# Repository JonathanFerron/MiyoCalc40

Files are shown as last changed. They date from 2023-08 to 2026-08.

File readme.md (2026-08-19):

# MiyoCalc40

RPN calculator

This is a project for a trough-hole only RPN calculator with a flexible configuration. The idea is for it to be minimalist, meant as a complement to other tools that the 
user would typically have on hand (computer, formula cheat sheet, etc.) rather than as a replacement, and made with easy to solder through-hole components.

I would like to give credit to the work of the following individuals which has served as inspiration for this project:

- Alex Garza for work done on the Voyager form-factor RPN calculators: https://paxer.net/voyager/
- Anton Poluektov for work done on the OpenRPNCalc calculator: https://github.com/apoluekt/OpenRPNCalc

The MiyoCalc40 **PCB work** is licensed under a
[Creative Commons Attribution-NonCommercial-ShareAlike 4.0 International License][cc-by-nc-sa].

[][cc-by-nc-sa]

[cc-by-nc-sa]: http://creativecommons.org/licenses/by-nc-sa/4.0/
[cc-by-nc-sa-image]: https://licensebuttons.net/l/by-nc-sa/4.0/88x31.png
[cc-by-nc-sa-shield]: https://img.shields.io/badge/License-CC%20BY--NC--SA%204.0-lightgrey.svg

The MiyoCalc40 **Firmware** is licensed under the GNU General Public License version 3:
Copyright (C) 2026 Jonathan Ferron

This program is free software: you can redistribute it and/or modify
it under the terms of the GNU General Public License as published by
the Free Software Foundation, either version 3 of the License, or (at your option) any later version.

This program is distributed in the hope that it will be useful,
but WITHOUT ANY WARRANTY; without even the implied warranty of
MERCHANTABILITY or FITNESS FOR A PARTICULAR PURPOSE.  See the
GNU General Public License for more details.

You should have received a copy of the GNU General Public License
along with this program.  If not, see <http://www.gnu.org/licenses/>.

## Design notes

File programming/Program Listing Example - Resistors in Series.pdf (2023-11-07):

Program Listing | Program Keycodes: 67 bytes in total
~~R
{- Calculate current and voltage drop through multiple resistors in series
Input: V(T) in X (stack) | I = V/R
R(i) in Rxn (registers)
Output: I(T) in X
V(i) in Rxn -}
0 | @@ R(T) initialized to 0.00 in X, V(T) pushed to Y | KC_0
ENTER | @@ R(T) pushed to Y, V(T) pushed to Z | KC_ENTER
FOR | @@ loop over rows 0 to 3 | KCP_FOR
CNT_INIT 1 # 0 | @@ Cnt1 = 0 | KCP_CNT_INIT KC_1 | KCP_NUMSEP KC_0
COUNT< 4 | @@ loop as long as Cnt1 is < 4 | KCP_CLESSN | KC_4
FOR | @@ loop over columns 0 to 9 | KCP_FOR
CNT_INIT 0 # 0 | @@ Cnt0 = 0 | KCP_CNT_INIT KC_0 | KCP_NUMSEP KC_0
COUNT< 10 | @@ loop as long as Cnt0 is < 10 | KCP_CLESSN | KC_1 | KC_0
RCL CNTREF 1 CNTREF 0 | @@ Pull R(i)(j)=R(Cnt1)(Cnt0) into X | KC_RCLREG | KCP_CNT_REF KC_1 | KCP_CNT_REF KC_0
IF X<>0 | KCP_IF | KCP_XNOT0
+ | @@ iteratively calc R(T) += R(i,j) | KC_ADD
ELSE | KCP_ELSE
CYCLE | @@ silly example to show use of CYCLE instruction | KCP_CYCLE
ENDIF | KCP_ENDIF
NEXT 1 | @@ next column | KCP_NEXT | KC_1
NEXT 1 | @@ next row | KCP_NEXT | KC_1

{- R(T) now in X. Calculate I, duplicate it to Y, and use it to calc the V(i) -}
/ | @@ I in X, R(T) in Y | KC_DIV
ENTER | @@ I in X and Y, R(T) in Z | KC_ENTER
FOR | @@ loop over rows 0 to 3 | KCP_FOR
CNT_INIT 1 # 0 | @@ Cnt1 = 0 | KCP_CNT_INIT KC_1 | KCP_NUMSEP KC_0
COUNT< 4 | @@ loop as long as Cnt1 is < 4 | KCP_CLESSN | KC_4
FOR | @@ loop over columns 0 to 9 | KCP_FOR
CNT_INIT 0 # 0 | @@ Cnt0 = 0 | KCP_CNT_INIT KC_0 | KCP_NUMSEP KC_0
COUNT< 10 | @@ loop as long as Cnt0 is < 10 | KCP_CLESSN | KC_1 | KC_0
RCL CNTREF 1 CNTREF 0 | @@ Pull R(i)(j)=R(Cnt1)(Cnt0) into X | KC_RCLREG | KCP_CNT_REF KC_1 | KCP_CNT_REF KC_0
* | @@ Calc V(i) in X, I in Y, R(T) in Z | KC_MULT
STO CNTREF 1 CNTREF 0 | @@ Store V(i) in Reg(i)(j) | KC_STOREG | KCP_CNT_REF KC_1 | KCP_CNT_REF KC_0
DROP | @@ Drop X: I will be in X, R(T) in Y | KC_DROPX
ENTER | @@ Duplicate I into Y, push R(T) to Z | KC_ENTER
NEXT 1 | @@ next column | KCP_NEXT | KC_1
NEXT 1 | @@ next row | KCP_NEXT | KC_1
DROP | @@ Drop duplicate I | KC_DROPX

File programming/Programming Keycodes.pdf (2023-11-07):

KCP_IF | 0xD0 | KCP_XEQU0 | 0xE0 // x=0?
KCP_ELSE | 0xD1 | KCP_XNOT0 | 0xE1 // x <> 0?
KCP_ENDIF | 0xD2 | KCP_XLESS0 | 0xE2 // x < 0?
| | KCP_XLEEQ0 | 0xE3 // x <= 0?
KCP_CASE | 0xD3 | KCP_XGREA0 | 0xE4 // x > 0?
KCP_WHEN | 0xD4 | KCP_GREQ0 | 0xE5 // x >= 0?
KCP_OTHER | 0xD5
KCP_ENDCAS | 0xD6 // end case | KCP_XEQUY | 0xE6 // x = y?
| | KCP_CEQUN | 0xE6 // cnt = n?
KCP_SETFLAG 0xD7 | KCP_XNOTY | 0xE7 // x <> y?
KCP_CLRFLAG 0xD8 | KCP_CNOTN | 0xE7
| | KCP_XLESSY | 0xE8
KCP_FOR | 0xD9 | KCP_CLESSN | 0xE8
KCP_NEXT | 0xDA | KCP_XLEEQY | 0xE9
| | KCP_CLEEQN | 0xE9
KCP_WHILE | 0xDB | KCP_XGREAY | 0xEA
KCP_WEND | 0xDC | KCP_CGREAN | 0xEA
| | KCP_XGREQY | 0xEB
KCP_DO | 0xDD | KCP_CGREQN | 0xEB
KCP_LOOPWHEN 0xDE
| | KCP_CNT_INIT
KCP_CYCLE | 0xEC | KCP_CNT_INC
KCP_EXIT | 0xED | KCP_STK_REF
| | KCP_CNT_REF
KCP_NUMSEP (#)

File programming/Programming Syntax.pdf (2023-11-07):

IF
X?0 or X?Y or Flag(n) = True (provide flag number on next instruction) do something
ELSE | | (optional)
do something else
ENDIF

note: no special keycode for 'flag(n)=true', just use KC_O to KC_7

SF(n): To set flag to true, with 'n' provided as 'next instruction' n between 0 and 7 in a 8 bit flag register
CF(n): To set flag to false, with 'n' provided as 'next instruction'

CASE
var to test (0 means X, 1 means Y, ...)
WHEN
value 1 (integers only) then optional KCP_NUMSEP keycode (#) (only required if next stmt starts with a digit)
do something | | automatically convert speace or CR to 'NumSep' when keyed from PC
WHEN | 1+ 'when' stmts | present as Carriage Return (CR) on Calculator LCD
value 2 | | optionally can show # as well on computer
do something else
OTHER | other' is optional and must be at end
do another thing
ENDCAS

FOR
CNT_INIT i (counter identifier)
init count (16 bit signed integer)
COUNT?
n (signed integer) then optional # (NumSep)
Do stuff
NEXT
increment / decrement to count (signed integer) then optional #

CND_INIT i (optional)
WHILE
X?0 or X?Y or Flag(n) = True
do stuff
CNT_INC i n # (optional, to increment Cnt(i) by n) WEND

DO
do stuff
LOOPWH
X?0 or X?Y or Flag(n) = True

EXIT instruction: force loops to return
CYCLE instruction: to force loops to loop

CNT_REF by itself, will push CNT(i) to X on the stack

@@ single line comment
{- multiple line comment -}
~~A to mark beginning of program A

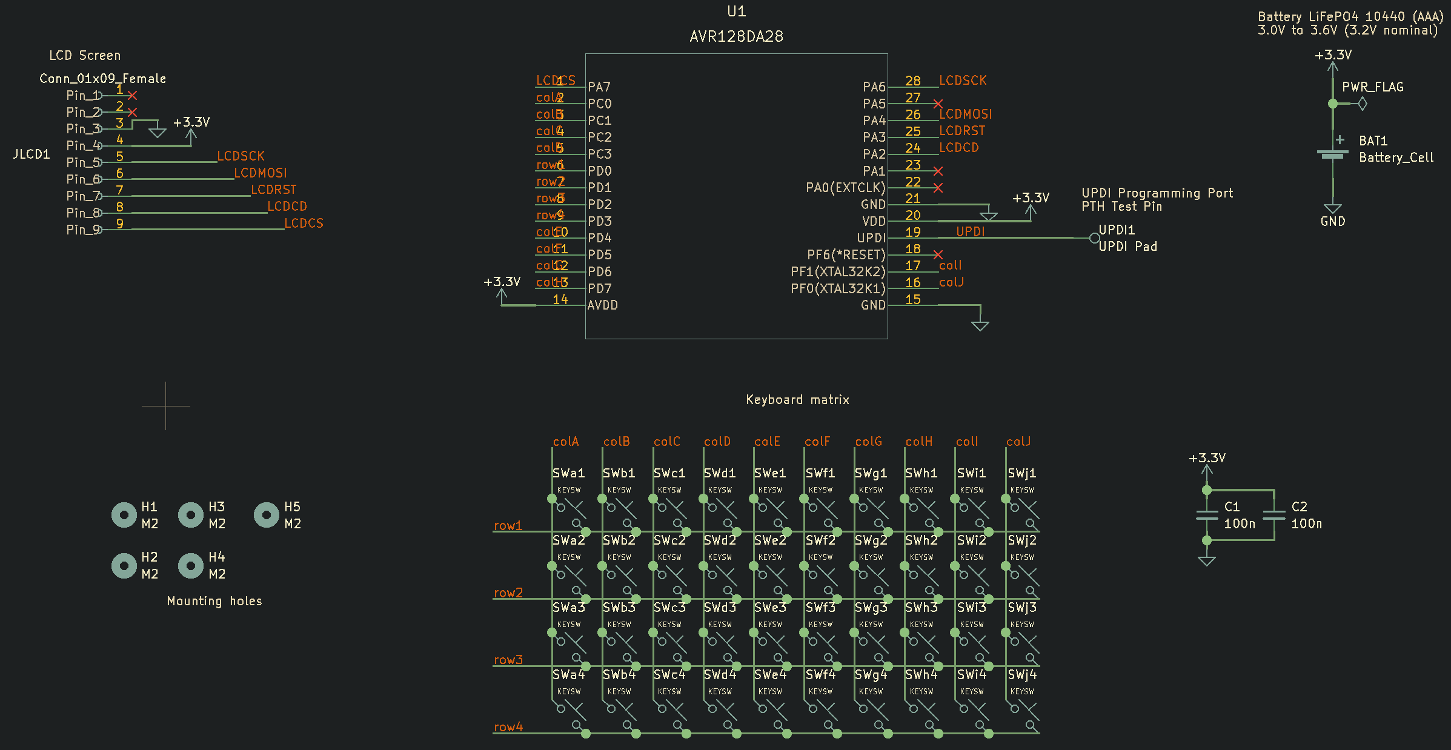
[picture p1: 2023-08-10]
pcb/printouts/Screenshot schematic.png

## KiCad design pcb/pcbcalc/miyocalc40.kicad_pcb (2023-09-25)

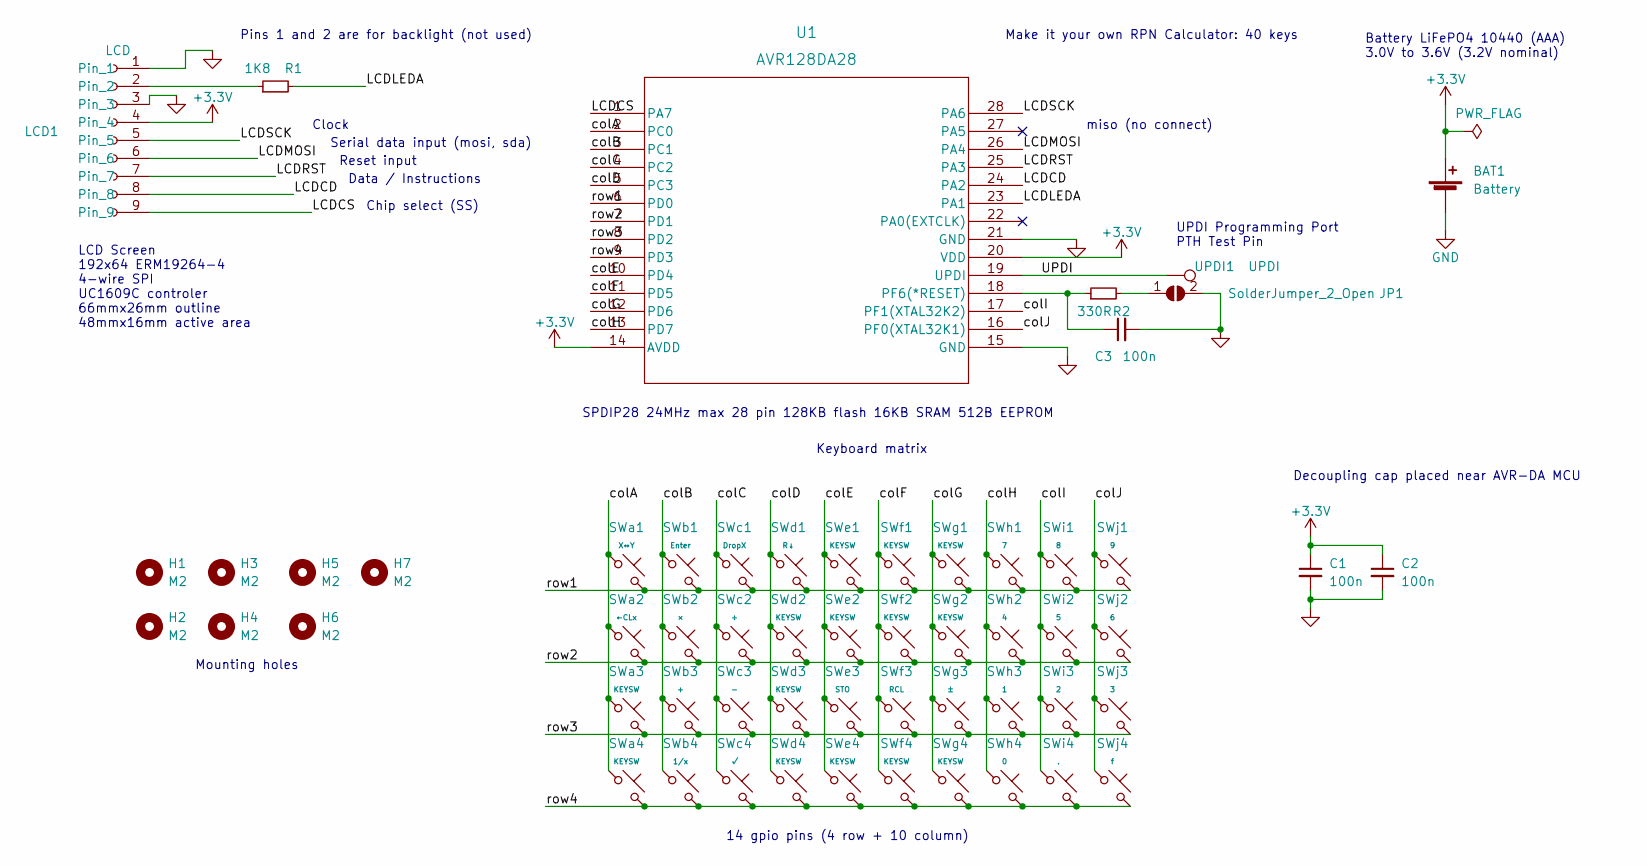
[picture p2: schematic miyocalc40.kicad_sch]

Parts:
BAT1: Battery; BatteryHolder_AAA
C1, C2, C3: 100n; C_Disc_D4.3mm_W1.9mm_P5.00mm
H1, H2, H3, H4, H5, H6, H7: M2; MountingHole
JP1: SolderJumper_2_Open; Reset Jumper
LCD1: LCD; PinSocket_1x09_P2.54mm_Vertical
R1: 1K8; R_Axial_DIN0204_L3.6mm_D1.6mm_P5.08mm_Horizontal
R2: 330R; R_Axial_DIN0204_L3.6mm_D1.6mm_P5.08mm_Horizontal
SWa1: X↔Y; SW_PUSH_6mm
SWa2: ←CLx; SW_PUSH_6mm
SWa3, SWa4: KEYSW; SW_PUSH_6mm
SWb1: Enter; SW_PUSH_6mm
SWb2: ×; SW_PUSH_6mm
SWb3: +; SW_PUSH_6mm
SWb4: 1/x; SW_PUSH_6mm
SWc1: DropX; SW_PUSH_6mm
SWc2: ÷; SW_PUSH_6mm
SWc3: -; SW_PUSH_6mm
SWc4: √; SW_PUSH_6mm
SWd1: R↓; SW_PUSH_6mm
SWd2, SWd3, SWd4: KEYSW; SW_PUSH_6mm
SWe1, SWe2, SWe4: KEYSW; SW_PUSH_6mm
SWe3: STO; SW_PUSH_6mm
SWf1, SWf2, SWf4: KEYSW; SW_PUSH_6mm
SWf3: RCL; SW_PUSH_6mm
SWg1, SWg2, SWg4: KEYSW; SW_PUSH_6mm
SWg3: ±; SW_PUSH_6mm
SWh1: 7; SW_PUSH_6mm
SWh2: 4; SW_PUSH_6mm
SWh3: 1; SW_PUSH_6mm
SWh4: 0; SW_PUSH_6mm
SWi1: 8; SW_PUSH_6mm
SWi2: 5; SW_PUSH_6mm
SWi3: 2; SW_PUSH_6mm
SWi4: .; SW_PUSH_6mm
SWj1: 9; SW_PUSH_6mm
SWj2: 6; SW_PUSH_6mm
SWj3: 3; SW_PUSH_6mm
SWj4: f; SW_PUSH_6mm
U1: AVR128DA28; DIP-28_W7.62mm_Socket
UPDI1: UPDI; UPDI Port

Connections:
+3V3: BAT1.1 (+), C1.1, C2.1, LCD1.4, U1.14 (AVDD), U1.20 (VDD)
/LCDCD: LCD1.8, U1.24 (PA2)
/LCDCS: LCD1.9, U1.1 (PA7)
/LCDLEDA: R1.2, U1.23 (PA1)
/LCDMOSI: LCD1.6, U1.26 (PA4)
/LCDRST: LCD1.7, U1.25 (PA3)
/LCDSCK: LCD1.5, U1.28 (PA6)
/UPDI: U1.19 (UPDI), UPDI1.1
/colA: SWa1.1, SWa2.1, SWa3.1, SWa4.1, U1.2 (PC0)
/colB: SWb1.1, SWb2.1, SWb3.1, SWb4.1, U1.3 (PC1)
/colC: SWc1.1, SWc2.1, SWc3.1, SWc4.1, U1.4 (PC2)
/colD: SWd1.1, SWd2.1, SWd3.1, SWd4.1, U1.5 (PC3)
/colE: SWe1.1, SWe2.1, SWe3.1, SWe4.1, U1.10 (PD4)
/colF: SWf1.1, SWf2.1, SWf3.1, SWf4.1, U1.11 (PD5)
/colG: SWg1.1, SWg2.1, SWg3.1, SWg4.1, U1.12 (PD6)
/colH: SWh1.1, SWh2.1, SWh3.1, SWh4.1, U1.13 (PD7)
/colI: SWi1.1, SWi2.1, SWi3.1, SWi4.1, U1.17 (PF1(XTAL32K2))
/colJ: SWj1.1, SWj2.1, SWj3.1, SWj4.1, U1.16 (PF0(XTAL32K1))
/row1: SWa1.2, SWb1.2, SWc1.2, SWd1.2, SWe1.2, SWf1.2, SWg1.2, SWh1.2, SWi1.2, SWj1.2, U1.6 (PD0)
/row2: SWa2.2, SWb2.2, SWc2.2, SWd2.2, SWe2.2, SWf2.2, SWg2.2, SWh2.2, SWi2.2, SWj2.2, U1.7 (PD1)
/row3: SWa3.2, SWb3.2, SWc3.2, SWd3.2, SWe3.2, SWf3.2, SWg3.2, SWh3.2, SWi3.2, SWj3.2, U1.8 (PD2)
/row4: SWa4.2, SWb4.2, SWc4.2, SWd4.2, SWe4.2, SWf4.2, SWg4.2, SWh4.2, SWi4.2, SWj4.2, U1.9 (PD3)
GND: BAT1.2 (-), C1.2, C2.2, C3.2, JP1.2 (B), LCD1.1, LCD1.3, U1.15 (GND), U1.21 (GND)
unnamed: C3.1, R2.1, U1.18 (PF6(*RESET))
unnamed: JP1.1 (A), R2.2
unnamed: LCD1.2, R1.1

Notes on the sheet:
Pins 1 and 2 are for backlight (not used)
miso (no connect)
Battery LiFePO4 10440 (AAA) 3.0V to 3.6V (3.2V nominal)
Decoupling cap placed near AVR-DA MCU
Clock
Make it your own RPN Calculator: 40 keys
Data / Instructions
Reset input
14 gpio pins (4 row + 10 column)
LCD Screen 192x64 ERM19264-4 4-wire SPI UC1609C controler 66mmx26mm outline 48mmx16mm active area
UPDI Programming Port PTH Test Pin
Serial data input (mosi, sda)
Keyboard matrix
Mounting holes
SPDIP28 24MHz max 28 pin 128KB flash 16KB SRAM 512B EEPROM
Chip select (SS)

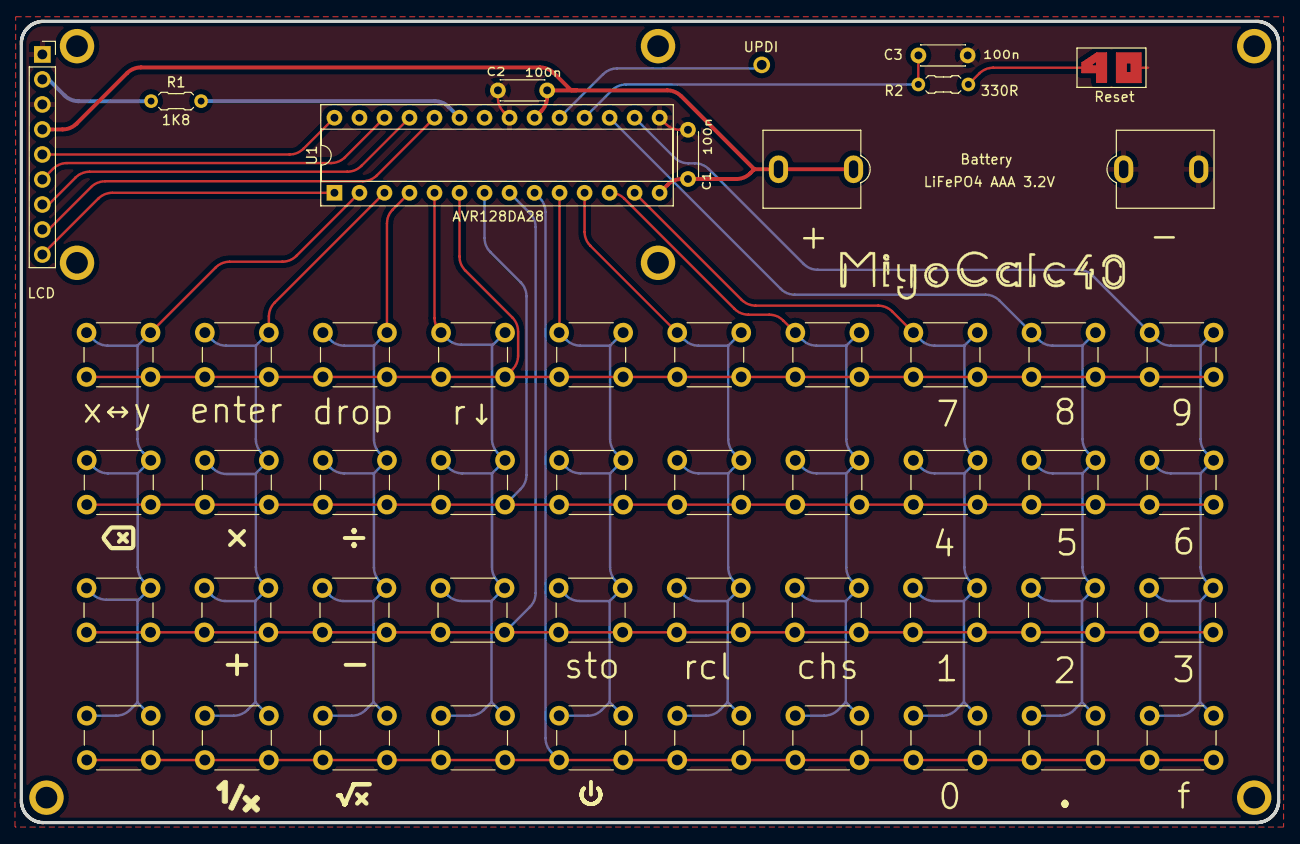
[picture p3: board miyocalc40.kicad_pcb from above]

Board: 2 copper layers, 127.7 x 81.4 mm, 57 parts (0 on the bottom side), 26 nets.

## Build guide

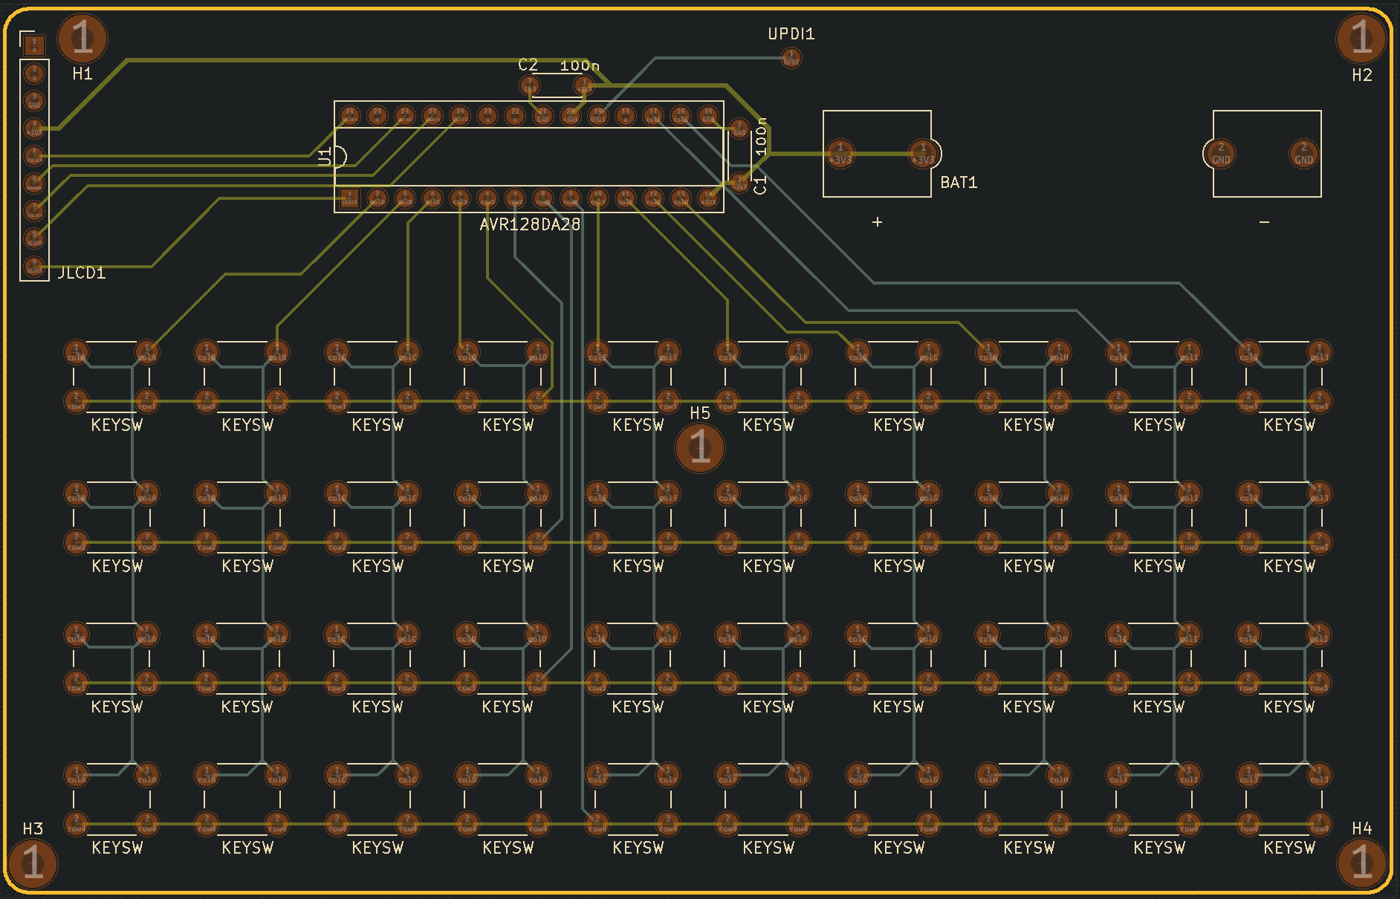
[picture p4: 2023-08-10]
pcb/printouts/Screenshot pcb.png

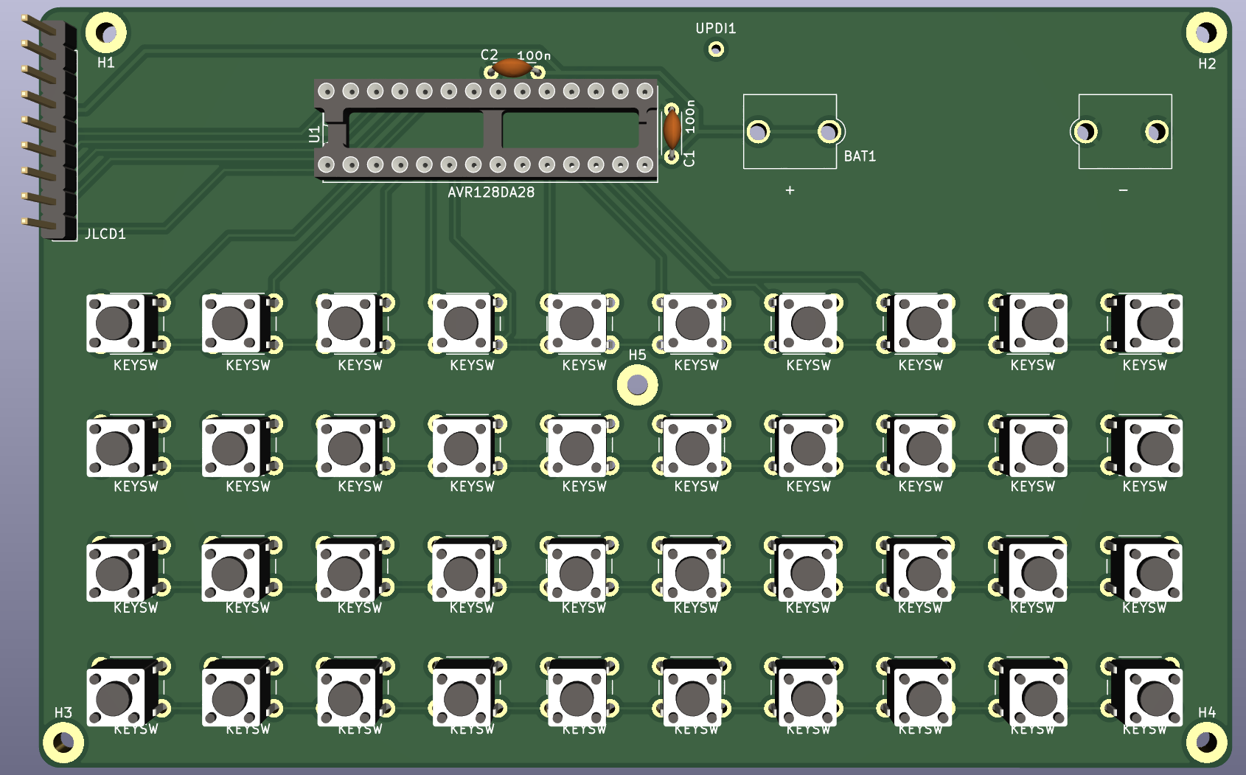
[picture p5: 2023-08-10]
pcb/printouts/miyocalc40 3D.png

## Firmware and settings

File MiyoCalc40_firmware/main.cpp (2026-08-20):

/*
   To build and flash the firmware: `make` then `make flash` from MiyoCalc40_firmware/ (see
   CLAUDE.md and makefile for the full make target list).

   main: main program loop

   matrix: matrix scanning code

   cards: contains mapping from matrix key positions to 'actions' for each 'mode'

   calc: number crunching mode

   lcd: to control lcd

   fonts: fonts bitmaps

   programming: programming mode

   config: configuration mode
     util: to display battery voltage, etc

   backlight: to turn on/off backlight and set pwm duty cycle

   avrducore: clock/CCP/fuses/GPIO/SPI0
*/

/* Other notes:

  MCU draws about 6.0mA at 3.2V when actively running at 24 MHz

*/

#include <stdbool.h>
#include <avr/io.h>
#include <avr/interrupt.h>
#include <avr/sleep.h>
#include <util/delay.h>

#include "matrix.h"
#include "lcd.h"
#include "main.h"
#include "cards.h"
#include "calc.h"
#include "util.h"
#include "clock.h"
#include "gpio.h"
#include "backlight.h"

#define LCD_Default_Contrast 0x0C // Default LCD constrast: 0x0A to 0x20 tend to work well.

// GPIO 5-wire SPI interface

#define LCD_CS GPIO_PIN(PORTA, 7)  // AVR pin connected to LCD CS pin
#define LCD_CD GPIO_PIN(PORTA, 2) // AVR pin connected to LCD CD pin
#define LCD_RST GPIO_PIN(PORTA, 3) // AVR pin connected to LCD Reset pin

// Global variables
ERM19264_UC1609_T  mylcd(LCD_CD, LCD_RST, LCD_CS); // construct object using hardware SPI: CD, RST, CS

int lcdon;  // to track if lcd is turned on or not, to do: change this to 'calcon'

int main()
{ clock_init(); // avrducore/clock.c: 24MHz OSCHF, no prescaler, CPUINT defaults

  /* Insert here any code that needs to run before interrupts are enabled but after all other core initialization. */
  sei();  // enable interrupts (could consider turning on interupts only after the setup code below, if it matters at all).

  setupMCU();
  setupMatrix();

  setupLCD();

  backlight_init();
  setupBattVoltMonitor();

  calc_init();

  for(;;)
    loop();
}

void setupMCU()
{ // ADC/AC/VREF setup for battery voltage monitoring lives in setupBattVoltMonitor() (util.cpp),
  // called from main(). The ADC itself is left disabled there; it's only enabled for the
  // duration of a reading, by read_batt_voltage_mv().

  set_sleep_mode(SLEEP_MODE_STANDBY);
  sleep_enable();
  /* Enable BOTHEDGES interrupts for columns */
  PORTC.PIN0CTRL |= PORT_ISC_BOTHEDGES_gc;
  PORTC.PIN1CTRL |= PORT_ISC_BOTHEDGES_gc;
  PORTC.PIN2CTRL |= PORT_ISC_BOTHEDGES_gc;
  PORTC.PIN3CTRL |= PORT_ISC_BOTHEDGES_gc;
  PORTD.PIN4CTRL |= PORT_ISC_BOTHEDGES_gc;
  PORTD.PIN5CTRL |= PORT_ISC_BOTHEDGES_gc;
  PORTD.PIN6CTRL |= PORT_ISC_BOTHEDGES_gc;
  PORTD.PIN7CTRL |= PORT_ISC_BOTHEDGES_gc;
  PORTF.PIN0CTRL |= PORT_ISC_BOTHEDGES_gc;
  PORTF.PIN1CTRL |= PORT_ISC_BOTHEDGES_gc;
}

ISR(PORTC_PORT_vect)
{ /* Clear interrupt flag */
  VPORTC.INTFLAGS = PIN0_bm | PIN1_bm | PIN2_bm | PIN3_bm;
}

ISR(PORTD_PORT_vect)
{ /* Clear interrupt flag */
  VPORTD.INTFLAGS = PIN4_bm | PIN5_bm | PIN6_bm | PIN7_bm;
}

ISR(PORTF_PORT_vect)
{ /* Clear interrupt flag */
  VPORTF.INTFLAGS = PIN0_bm | PIN1_bm;
}


void setupLCD()
{ mylcd.LCDbegin(LCD_Default_Contrast); // initialize the LCD
  mylcd.LCDFillScreen(0x00, 0); // clear screen
  _delay_ms(50);
  lcdon = true;
}

/*
  go in sleep mode (enable sleep, enable bothedges interrups for all column pins) : see dxcore/megaavr/extras/powersave.md

  upon wake interupt (port isr wake-up button press wakes up the mcu from sleep)
  debounce 3ms to 20ms (10 times 2ms) using PIT (periodic interupt timer, programmed to trigger an interrupt every millisecond, lowpower_delay_ms function, set interrupt
  to fire every 32 RTC clock cycles and enable PIT, enable PIT interrupts), validating logic low level on a column each time: btn_debounce() function

  if logic low level still detected in a column
    then scan keys (scan matrix) via function call: scankb()

    if calc is off, power it up if 'on' button was pressed
    else (lcd is on)
      if in mem store, recall mode or clear mode (see the mem_recall_mode, mem_store_mode and mem_clear_mode boolean variables):
        call mem store, recall, or clear with key pos (2D), should have a max of 40 possible var : call apply_memory_rcl(uint8_t r, uint8_t c), apply_memory_sto(uint8_t r, uint8_t c) and apply_memory_clr(uint8_t r, uint8_t c)
      else
        with key position (from scankb), lookup function pointer and keycode (action struct)

        if in 'calc mode'
          if 'off' button (combination) was pressed (can tell based on action), power down
          else
            process action via function call (from function pointer): from 'action' struct from 'calc' (if in calc mode) or 'config' (if in config mode)
              provide it the keycode that was also looked up
              action in program mode, when a key is pressed to be recorded, is a function that will call another function with a keycode to log/record it
          end if
        end if
      end if
    endif

    inner loop begin (idle until key is released):
      if logic low level on any column still
        then sleep
          port isr wake-up: button is released
      end if
    end inner loop
    may want to debouce here as well (openrpncalc uses 10ms)
  end if
*/
bool press_valid = false;
void loop()
{ // go in sleep mode
  sleep_cpu();

  // debounce 10 * 2ms = 20ms
  press_valid = true;
  for(uint8_t i = 0; i < 10; i++)
  { // initialize before scanning
    keypos_c = 0xff;
    keypos_r = 0xff;
    scanKB(); // scan kb
    /* If no button is pressed, flag press as non-valid */
    if(keypos_c == 0xff && keypos_r == 0xff)
    { press_valid = false;
      break;
    }
    //lp_delay_ms(2);
    _delay_ms(2);  // to-do: chg this to PIT based delay to save power
  }  // end for loop for debouncing

  // if key press is valid, then move on to scan and process key press
  if(press_valid)
  { // scan keys
    scanKB();

    // if lcd is off, power it up if 'on' button was pressed
    if(keypos_r == ONOFFKEYPOS_R && keypos_c == ONOFFKEYPOS_C && !lcdon)
    { setupLCD();
      backlight_resume();
      lcdon = true;
      if(input.started)
        LCDDrawInput();
      else
        LCDDrawStackAndMem();

      set_sleep_mode(SLEEP_MODE_STANDBY);
      shift = baseLayer;
      keypos_c = 0xff;
      keypos_r = 0xff; // reset keypos to 'null' after action is obtained
    } // 'power on' lcd

    // if non-null keypos and calc is on:
    if(lcdon && keypos_r != 0xff)
    { // if in mem store, recall mode or clear mode
      if(mem_recall_mode || mem_store_mode || mem_clear_mode)
      { if(mem_recall_mode)
        { // process action
          // call apply_memory_rcl(uint8_t r, uint8_t c) to recall the variable to X
          apply_memory_rcl(keypos_r, keypos_c);
          keypos_c = 0xff;
          keypos_r = 0xff; // reset keypos to 'null' after action is obtained

          // reset mode to false after action has been processed
          mem_recall_mode = false;
        }
        else if(mem_store_mode)
        { // process action
          apply_memory_sto(keypos_r, keypos_c);
          keypos_c = 0xff;
          keypos_r = 0xff; // reset keypos to 'null' after action is obtained

          // reset mode to false after action has been processed
          mem_store_mode = false;
        }
        else // we're in mem clear mode
        { // process action
          apply_memory_clr(keypos_r, keypos_c);
          keypos_c = 0xff;
          keypos_r = 0xff; // reset keypos to 'null' after action is obtained

          // reset mode to false after action has been processed
          mem_clear_mode = false;
        }
        LCDDrawCalcStatus();
      }
      else // not in mem store, recall, or clear mode
      { // lookup function pointer+keycode (action struct)
        action current_action = keytoaction();
        // refresh lcd : this will become obsolete since we'll refresh the lcd from within the actions, when necessary
        /*
          mylcd.LCDFillScreen(0x00, 0); // clear screen
          mylcd.LCDChar('R' - MCFLETOFFSET, 14*0, 0*3);  // R
          mylcd.LCDChar(keypos_r, 14*1, 0 * 3);
          mylcd.LCDChar('C' - MCFLETOFFSET, 14*3, 0*3); // C
          mylcd.LCDChar(keypos_c, 14*4, 0 * 3);
        */

        keypos_c = 0xff;
        keypos_r = 0xff; // reset keypos to 'null' after action is obtained

        // process action via function call: from 'action' struct, call the function and provide it the keycode that was also looked up.
        current_action.fct(current_action.keycode);

        // if (current shift is not base layer && keycode of function that was just executed is not a layer shift keycode that corresponds to the current layer), then move back to base layer
        // config mode has no shift layers of its own, and enter_shift_base() would repaint the
        // calc status indicators over whatever config screen is currently displayed, so skip
        // all of this while in config mode.
        if(current_calc_prog_config_mode != config_mode)
        { if(!((current_action.mnemonic[0] == ACT_SHFT_F.mnemonic[0] && current_action.mnemonic[1] == ACT_SHFT_F.mnemonic[1] && shift == fLayer) ||
               (current_action.mnemonic[0] == ACT_SHFT_G.mnemonic[0] && current_action.mnemonic[1] == ACT_SHFT_G.mnemonic[1] && shift == gLayer) ||
               (current_action.mnemonic[0] == ACT_SHFT_H.mnemonic[0] && current_action.mnemonic[1] == ACT_SHFT_H.mnemonic[1] && shift == hLayer)))
          { if(lcdon)
              enter_shift_base(KC_NOP);
            else
              shift = baseLayer;
          }
        }
        else
          shift = baseLayer;
      }

      do
      { keypos_c = 0xff;
        keypos_r = 0xff;
        scanKB();
      }
      while(keypos_c != 0xff || keypos_r != 0xff);

    } // end processing of non-null keypos
  } // end processing of valid key press

} // loop()

// Battery voltage measurement (setupBattVoltMonitor() / read_batt_voltage_mv()) now lives in
// util.cpp, wired up to the 'config' mode battery-voltage screen (config.cpp). See util.cpp for
// the derivation of the VDD-in-millivolts calculation and the peripheral setup this depends on.

// if 'off' button (combination) was pressed (can tell based on action), power down lcd and configure 'sleep mode' to powerdown
void power_down(__attribute__((unused)) uint8_t keycode)
{ mylcd.FullLCDPowerDown();
  backlight_suspend(); // see backlight.h: TCA0 must not be left running into Power-Down sleep
  lcdon = false;
  //LCDDrawStackAndMem();

  set_sleep_mode(SLEEP_MODE_PWR_DOWN);
} // power_down()

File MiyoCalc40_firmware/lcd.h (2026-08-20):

/*
   Based in part on code from the ERM19264_UC1609 project by Gavin Lyons: https://github.com/gavinlyonsrepo/ERM19264_UC1609
*/

#ifndef LCD_H
#define LCD_H

#include <stdint.h>
#include "gpio.h"

// Display Pixel colours   definition
// black on white, FG = black BG = white
// ERM19264FS-4 LCD Display Black on White
#define FOREGROUND  0
#define BACKGROUND 1
#define INVERSE 2

// UC1909 Read registers
#define UC1609_GET_STATUS 0xFE

// UC1909 Write registers
#define UC1609_SYSTEM_RESET 0xE2

#define UC1609_POWER_CONTROL 0x28
#define UC1609_PC_SET 0x06 // PC[2:0] 110 Internal V LCD (7x charge pump) + 10b: 1.4mA

#define UC1609_ADDRESS_CONTROL 0x88 // set RAM address control
#define UC1609_ADDRESS_SET 0x02 // Set AC [2:0] Program registers  for RAM address control.

#define UC1609_SET_PAGEADD 0xB0 // Page address Set PA[3:0]
#define UC1609_SET_COLADD_LSB 0x00 // Column Address Set CA [3:0]
#define UC1609_SET_COLADD_MSB 0x10 // Column Address Set CA [7:4]

#define UC1609_TEMP_COMP_REG 0x27 // Temperature Compensation Register
#define UC1609_TEMP_COMP_SET 0x00 // TC[1:0] = 00b= -0.00%/ C

#define UC1609_FRAMERATE_REG 0xA0 // Frame rate
#define UC1609_FRAMERATE_SET 0x01  // Set Frame Rate LC [4:3] 01b: 95 fps

#define UC1609_BIAS_RATIO 0xE8 // Bias Ratio. The ratio between V-LCD and V-D .
#define UC1609_BIAS_RATIO_SET 0x03 //  Set BR[1:0] = 11 (set to 9 default)

#define UC1609_GN_PM 0x81 // Set V BIAS Potentiometer to fine tune V-D and V-LCD  (double-byte command)
#define UC1609_DEFAULT_GN_PM 0x49 // default only used if user does not specify Vbias

#define UC1609_LCD_CONTROL 0xC0 // Rotate map control
#define UC1609_DISPLAY_ON 0xAE // enables display
#define UC1609_ALL_PIXEL_ON 0xA4 // sets on all Pixels on
#define UC1609_INVERSE_DISPLAY 0xA6 // inverts display
#define UC1609_SCROLL 0x40 // scrolls , Set the scroll line number. 0-64

// Rotate
#define UC1609_ROTATION_FLIP_TWO 0x06
#define UC1609_ROTATION_NORMAL 0x04
#define UC1609_ROTATION_FLIP_ONE 0x02
#define UC1609_ROTATION_FLIP_THREE 0x00

// Delays
// Delays
// mS , datasheet FIG 11 wait <=  3mS
#define UC1609_POWERON_DELAY1  3
// mS, datasheet FIG 11 wait >=  3uS
#define UC1609_POWERON_DELAY2  50
// mS  datasheet FIG 11 wait >= 5mS  , Does not work on SW SPI blue
#define UC1609_POWERON_DELAY3  0

#define UC1609_INIT_DELAY 100 //  mS delay ,after init,


// No font
#ifdef UC_FONT_MOD_ONE
  #define UC1609_ASCII_OFFSET 0x00
#else
  #define UC1609_ASCII_OFFSET 0x20 //0x20, ASCII character for Space
#endif

#define UC1609_FONTPADDING  send_data(0x00)
#define UC1609_FONTWIDTH 5

// GPIO
#define UC1609_CS_SetHigh GPIO_HIGH(_LCD_CS)
#define UC1609_CS_SetLow GPIO_LOW(_LCD_CS)
#define UC1609_CD_SetHigh GPIO_HIGH(_LCD_CD)
#define UC1609_CD_SetLow GPIO_LOW(_LCD_CD)
#define UC1609_RST_SetHigh GPIO_HIGH(_LCD_RST)
#define UC1609_RST_SetLow GPIO_LOW(_LCD_RST)

// SPI: frequency/mode are fixed in avrducore/spi.c (6MHz, MSB-first, mode 0)

// Display  Size
const uint8_t LCD_WIDTH = 192;
const uint8_t LCD_HEIGHT = 64;

//class
class ERM19264_UC1609_T
{
public:
  // Contructor 1 Software SPI with explicit SCLK and SDIN
  ERM19264_UC1609_T(int8_t cd, int8_t rst, int8_t cs, int8_t sclk, int8_t din);
  // Constructor 2 Hardware SPI
  ERM19264_UC1609_T(gpio_pin_t cd, gpio_pin_t rst, gpio_pin_t cs);

  ~ERM19264_UC1609_T() {};

  void LCDGotoXY(uint8_t column, uint8_t page);
  void LCDString(const char* characters, uint8_t col, uint8_t page);
  void LCDbegin(uint8_t VbiasPot = UC1609_DEFAULT_GN_PM);
  void LCDinit(void);
  void LCDPowerDown(void);
  void FullLCDPowerDown(void);
  void LCDEnable(uint8_t on);
  void LCDFillScreen(uint8_t pixel, uint8_t mircodelay);
  void LCDFillPage(uint8_t pixels);
  void LCDBitmap(int16_t x, int16_t y, uint8_t w, uint8_t h, const uint8_t* data);
  void LCDSetContrast(uint8_t cont);
  void LCDChar(uint8_t index, uint8_t col, uint8_t page);
  void LCDDot(uint8_t col, uint8_t page);
  void LCDCharSeq(uint8_t indexes[], uint8_t size, uint8_t col, uint8_t page);

private:

  void send_data(uint8_t data);
  void send_command(uint8_t command, uint8_t value);

  gpio_pin_t _LCD_CS;
  gpio_pin_t _LCD_CD;
  gpio_pin_t _LCD_RST;
  uint8_t _VbiasPOT; // Contrast default 0x49 datasheet 00-FE
};

#endif

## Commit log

2023-08-17 PCB updates, mostly silkscreen tweaking
2023-08-20 PWM for backlight
2023-08-31 Small updates to pcb
    [miyocalc40.kicad_pcb]
2023-09-25 Multiple updates for rev 1.0
    [miyocalc40.kicad_pcb, miyocalc40base.kicad_pcb, miyocalc40base.kicad_sch]
2023-11-07 Prep work for programming mode
    [Programming Keycodes and Documentation.xlsx]
2026-08-05 Add CLAUDE.md with codebase guidance for Claude Code
    Documents the firmware/PCB split, Arduino+DxCore build/flash process,
    and firmware module architecture (main/matrix/cards/calc/lcd/programming/config).
2026-08-11 Fix LCDNumber() decimal display noise; add scientific notation
    Numbers like 3 and 11.06 rendered with float-imprecision noise
    (2.99999998, 11.0600001) due to three separate defects: convert_input()
    used pow(10, exponent), which is inexact for the negative-exponent case;
    LCDNumber() read an out-of-bounds max_mantissa[precision] array; and
    LCDNumber()'s own scaling relied on the same imprecise pow(). Replaced
    all three with an exact scale10()/p10[] table-driven helper.
    Also implements scientific notation for values outside the fixed-point
    window (previously a stub), and fixes an uninitialized number_for_lcd
    struct in LCDDrawInput() that left show_exponent/exponent as garbage
    stack values, cau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
2026-08-18 Implement config mode and battery voltage display
    Wires up the previously-inert config mode: keytoaction() now dispatches
    to config_cards when in config_mode, entry/exit is handled via
    enter_config_mode()/config_cancel_exit() in the new config.cpp, and
    returning to calc mode fully repaints the screen.
    Moves battery-voltage ADC setup/reading out of main.cpp's stale
    testBatteryVoltage() into util.cpp as setupBattVoltMonitor()/
    read_batt_voltage_mv(), with the ADC left disabled between readings
    for power savings, and lands it as the first real config action
    (BATT screen on r3,c4) with a corrected derivation comment. All
    config actions use KC_NOP, matching that config mode has no
    programmable f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
    [main.cpp, util.cpp]
2026-08-18 Fix -Wwrite-strings warnings in LCDString()
    LCDString() only reads through the char pointer, so take const char*
    instead of char* — clears the ISO C++ string-literal warning at every
    call site (config.cpp, main.cpp) instead of casting at each one.
    Verified the produced .hex is byte-for-byte identical before and
    after via arduino-builder, confirming this is a pure signature change
    with no codegen effect.
    [lcd.cpp, lcd.h]
2026-08-19 Port firmware off Arduino IDE + DxCore to a pure avr-gcc toolchain
    Replaces the Arduino IDE/DxCore build with a plain avr-gcc/g++ Makefile
    (MiyoCalc40_firmware/makefile), so the firmware can be edited in Kate and
    built/flashed entirely from the console via avrdude's serialupdi
    programmer, with no Arduino core or Python/pymcuprog dependency.
    New avrducore/ (mirrors the KeyDU-Citrouille90 project's conventions) is a
    hand-rolled replacement for what DxCore's init() used to provide silently:
    - clock.c/h: 24MHz OSCHF clock init via CCP-protected writes. Verified
    byte-identical to the value DxCore wrote for the same F_CPU.
    - fuses.c: fuse row cross-checked field by field against ioavr128da28.h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
    [lcd.cpp]
2026-08-19 Retire Arduino IDE/Geany project files, update CLAUDE.md for the make-based build
    Removes MiyoCalc40_firmware.ino, MiyoCalc40GeanyProj.{geany,tags}, and the
    DxCore.url/shortcut files -- all now obsolete after the avr-gcc/make port
    (previous commit), which is hardware-verified working.
    Moves the .ino's module-breakdown header comment into main.cpp (its new
    natural home) rather than losing it, and updates CLAUDE.md's "Firmware:
    build & flash" section for the make-based flow: toolchain versions, the
    make target list, avrducore/'s role, and clangd/Kate editor setup. Keeps
    the -mdouble=64 warning (still applies -- same avr-libc, and the makefile
    now makes that flag trivially easy to add by mista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
    [main.cpp]
2026-08-19 Fix -Wshadow warning, trim stale comments, add prog_cards placeholder
    calc.cpp: rename convert_input()'s local `shift` to `place` so it no
    longer shadows the global shift-layer state variable.
    cards.cpp: add a prog_cards placeholder table (mirroring calc_cards'
    layer structure) for future programming-mode keymaps, rename
    config_cards to config_card since only one config screen exists today,
    and trim comments that had gone stale.
    Also trims outdated Arduino/DxCore-era commentary in avrducore/,
    a stray leading space in lcd.h, and bumps the readme's copyright year.
    [lcd.h, spi.c]
2026-08-20 Implement PWM backlight with perceptual dimming, wire into config mode
    Adds a real backlight.cpp/h driver (TCA0 split 8-bit PWM on PA1), replacing the
    routing-only setupBacklight() stub. Brightness is addressed via a 20-notch
    perceptual (Weber-fraction geometric) table, the same approach used for the
    LED indicators in KeyDU-Citrouille90's led.c, so each notch reads as roughly
    the same perceived brightness step. RUNSTDBY is only set on TCA0 while the
    backlight is actually on and dimmed, since it's needed to keep the PWM running
    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
2026-08-20 Fix unit typo in power-down runtime comment
    0.0073uA was off by 1000x from the intended 7.3uA (0.0073mA); the resulting
    runtime figure (26 months) was already correct, only the unit label was wrong.
    [util.cpp]
2026-08-20 Apply astyle formatting
    Only lcd.h had drift since the last format pass: fixes _VbiasPOT's stray
    3-space indent. Also reverts an astyle quirk that re-added a leading space
    astyle wanted to put before the UC1609_INIT_DELAY #define, which conflicted
    with intentionally-removed trailing/leading whitespace there.
    [lcd.h]

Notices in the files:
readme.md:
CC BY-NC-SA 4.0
